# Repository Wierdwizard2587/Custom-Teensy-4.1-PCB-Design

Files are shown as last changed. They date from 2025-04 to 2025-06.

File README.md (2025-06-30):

# Custom Teensy 4.1 Microcontroller PCB

## Overview

This repository covers the design of my custom take on the Teensy 4.1 from PJRC. [Teensy 4.1 Site](https://www.pjrc.com/store/teensy41.html). I took inspiration from [jenschrs design](https://github.com/jenschr/Teensy-4.1-example) who incorporated usb-c rather than the intended USB-Micro, but lacked the SD slot, expandable RAM and flash memory, and PHY Ethernet IC and RJ45 Connection Like the original. 

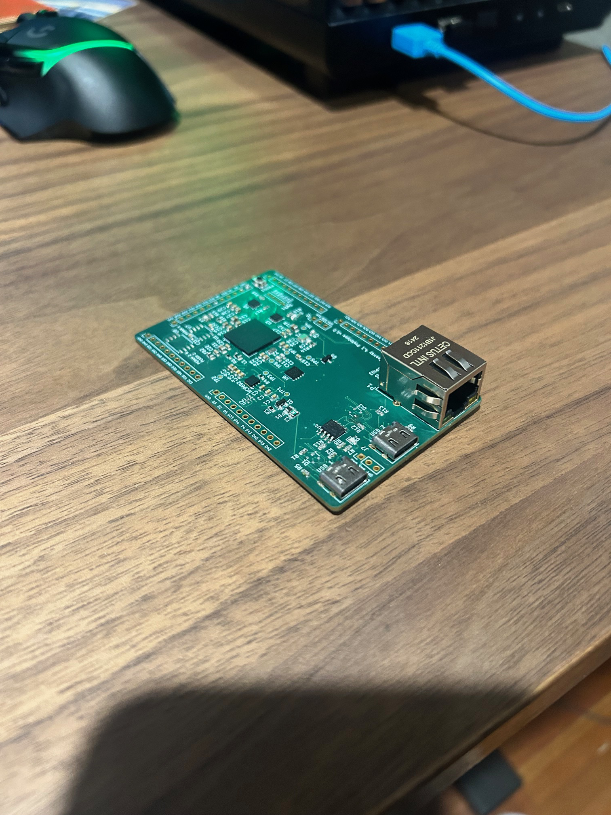
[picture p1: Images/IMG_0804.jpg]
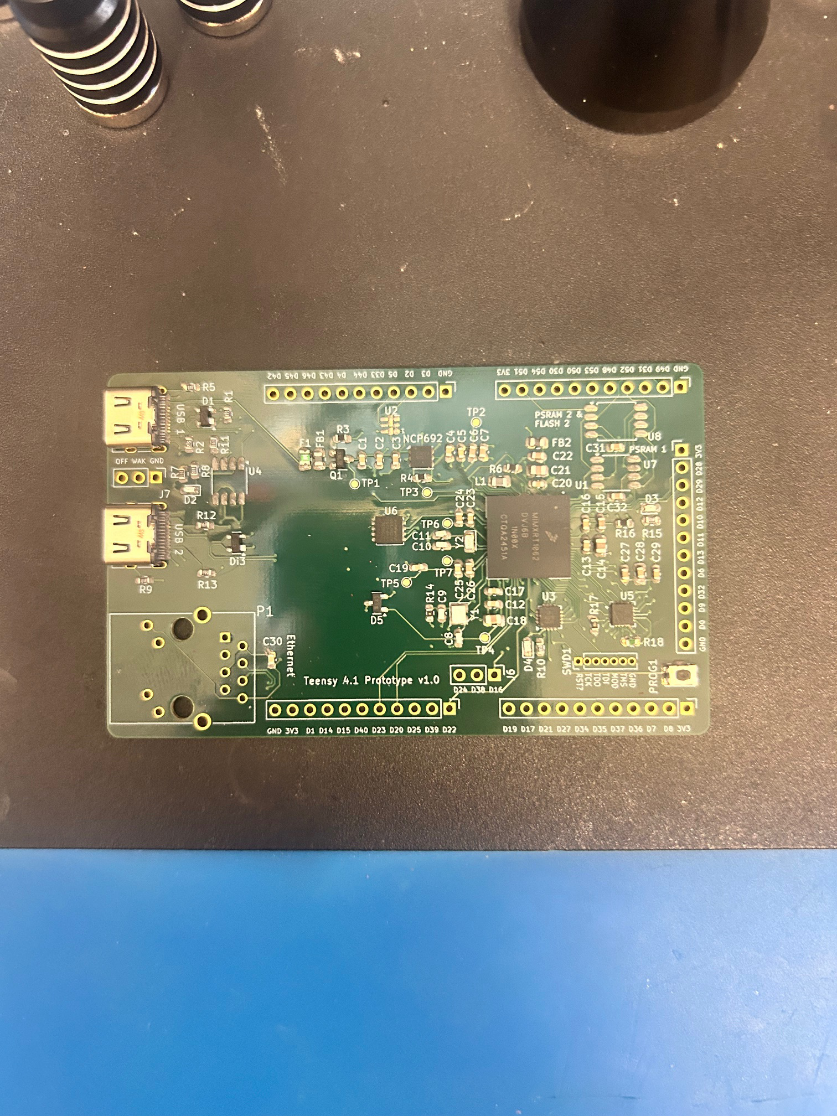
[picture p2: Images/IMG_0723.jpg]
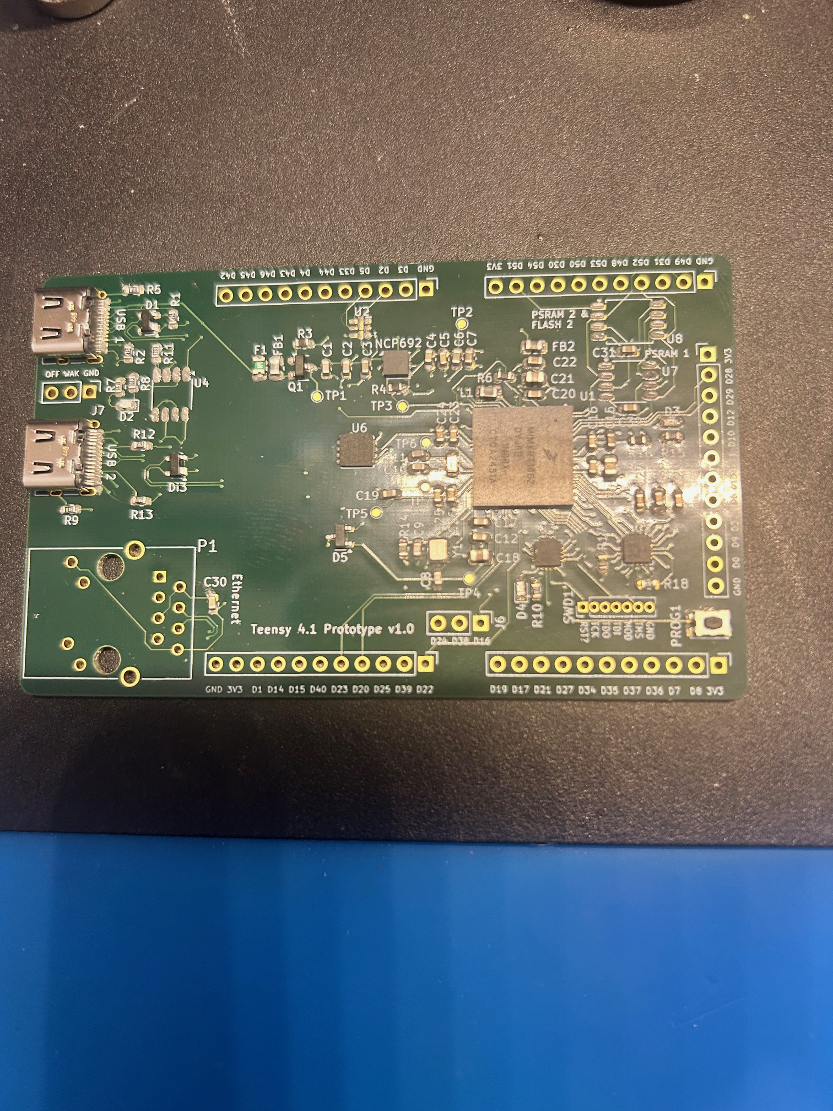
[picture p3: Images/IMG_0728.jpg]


This Design, following the Teensy 4.1 official Schematic Features a 6 layer design with dedicated GND and 3.3V plane’s, and possesses the same RAM, Flash, Boot loader and MCU components as the original Teensy 4.1, but the 3.3V regulator was swapped for a NCP692 regulator providing essentially the same specs. 

The Following are notable features in the Boards design:

- 2x USB-C connections, one for serial programming and power, and the other a host port for communication with serial to other devices
- Expandable IC footprints for a combination of either 2x additional 16mb PSRAM or 1x 16mb PSRAM and 1x 64mb FLASH
- DP83825L Ethernet PHY IC for interfacing with the MCU and the RJ45 Ethernet connector attached to the board for 10/100mbps internet
- micro SD slot

After assembling the first prototype with the supplied stencil from JLCPCB and a hot plate, and resolving a short issue from a solder bridge, The bootloader flashed the blink script to the memory and the board was able to achieve it, however serial communication wouldn’t work and windows device manager gave a error code 43. After a week of researching and forum questioning, I was able to locate the root problem to the ESD protection Diodes on the USB-C that I had used were rated for USB 2.0 and not 3.0, which was ruining the serial communication between my PC and the board. After desoldering these the board managed to show up on my PC and was finally able to communicate with it, albeit without ESD protection which can be replaced with a more suitable diode.

The Designing and assembly of this board taught me more design and assembly concepts such as:

- differential pairs and length matching design
- separation of analog and digital traces and components
- EMI ground shielding techniques
- positioning and selection of decoupling capacitors for electronic noise protection
- common via practices
- practice soldering SMD components with a hot plate and stencil effectively without overheating the temperature sensitive IC’s 
- more practical experience isolating faults in a circuit, such as isolating shorts, identifying faulty components
- examining signals with an oscilloscope to ensure Ethernet signal integrity.

all while managing to keep the design cost effective. This board is the most complex I have designed and successfully assembled to date and I am eager to take these skills learnt to the next level with the next project the future brings.

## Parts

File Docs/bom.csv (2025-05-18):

Designator | Footprint | Quantity | Value | LCSC Part #
C1, C12, C13, C17, C19, C2, C20, C23, C25, C31, C32, C4 | 0603 | 12 | 0.22uf | CC0603KRX7R6BB224
C10, C11 | 0603 | 2 | 9pF
C14, C18, C21 | 0805 | 3 | 10uf | GRM21BR71A106KA73K
C15, C22, C24, C26, C6 | 0603 | 5 | 4.7uf | CL10B475KQ8NQNC
C16, C5 | 0603 | 2 | 10nf | 0603B103K160CT
C27 | 0603 | 1 | 2.2uf | CC0603KRX7R6BB224
C28 | 0805 | 1 | 0.22uf | GRM21BR71A106KA73K
C29 | 0603 | 1 | 10nf | CL10B475KQ8NQNC
C3, C7 | 0603 | 2 | 2.2uf | CL10B225KP8NNNC
C30 | 0603 | 1 | 0.1uF | CC0603KRX7R6BB224
C8, C9 | 0603 | 2 | 10pF
D1, DI3 | SOT-143 | 2 | SP0503BAHT
D2, D3, D4 | 0603 | 3 | LED
D5 | SOT-23 | 1 | BAT54C
F1 | 0805 | 1 | Fuse | 0ZCK0050FF2E
FB1, FB2 | 0805 | 2 | Ferrite_Bead | FBMH2012HM121-T‎
J1, J2, J4, J5 | PinHeader_1x11_P2.54mm_Vertical | 4 | Conn_01x11_Male
J3 | PinHeader_1x12_P2.54mm_Vertical | 1 | Conn_01x12_Male
J6, J7 | PinHeader_1x03_P2.54mm_Vertical | 2 | Conn_01x03_Male
J8 | microSD_HC_Hirose_DM3AT-SF-PEJM5 | 1 | Micro_SD_Card
L1 | 0805 | 1 | 4.7uH | LQM21PN4R7MGRD
NCP692 | DFN-6-1EP_3x3mm_P0.95mm_EP1.7x2.6mm | 1 | OnSemi NCP692, fixed version | NCP692MN33T2G
P1 | J1B1211CCD | 1 | J1B1211CCD
PROG1 | SW_Push_1P1T-SH_NO_CK_KMR2xxG | 1 | SW_Push | KMR241GLFS
Q1 | SOT-23 | 1 | Q_PMOS_GDS_DMP3125L
R1, R2 | 0603 | 2 | 5.1k | RC0603FR-075K1L
R10, R15, R8 | 0603 | 3 | 1k
R11, R7 | 0603 | 2 | 16k
R12, R13 | 0603 | 2 | 56k | RMCF0603FT56K0
R14 | 0603 | 1 | 2.2M
R16, R3, R4, R6 | 0603 | 4 | 100k
R17 | 0603 | 1 | 150R
R18 | 0603 | 1 | 6.49K
R5, R9 | 0603 | 2 | 1M
SWD1 | PinHeader_1x07_P1.27mm_Vertical | 1 | SWD
TP1, TP2, TP3, TP4, TP5, TP6, TP7 | TestPoint_Pad_D1.0mm | 7 | TestPoint
U1 | BGA196C80P14X14_1200X1200X152N | 1 | MIMXRT1062DVJ6B
U2 | LED-APA102-2020 | 1 | opto_APA102-2020
U3 | QFN-16-1EP_3x3mm_P0.5mm_EP1.9x1.9mm | 1 | MKL02Z32VFG4
U4 | SO-8_3.9x4.9mm_P1.27mm | 1 | MAX1562
U5 | XCVR_DP83825IRMQR | 1 | DP83825IRMQR
U6 | XSON8_4x4mm | 1 | W25Q64JVXGIM
U7 | SOP-8_3.9x4.9mm_P1.27mm | 1 | PSRAM APS640L 3SQR (1)
U8 | SOIC-8_5.3x5.3mm_P1.27mm | 1 | 2nd PSRAM/Flash APS640L 3SQR / 25q128JVSQ (2)
USB_DFP1, USB_UFP1 | USB_C_Receptacle_HRO_TYPE-C-31-M-12 | 2 | USB_C_Receptacle_USB2.0
Y1 | Crystal_SMD_2520-4Pin_2.5x2.0mm | 1 | 24MHz
Y2 | Crystal_SMD_TXC_9HT11-2Pin_2.0x1.2mm_HandSoldering | 1 | 32.768kHz

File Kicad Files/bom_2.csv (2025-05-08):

Reference | Value | Footprint
C1 | 0.22uf | Capacitor_SMD:C_0603_1608Metric
C2 | 0.22uf | Capacitor_SMD:C_0603_1608Metric
C3 | 2.2uf | Capacitor_SMD:C_0603_1608Metric
C4 | 0.22uf | Capacitor_SMD:C_0603_1608Metric
C5 | 10nf | Capacitor_SMD:C_0603_1608Metric
C6 | 4.7uf | Capacitor_SMD:C_0603_1608Metric
C7 | 2.2uf | Capacitor_SMD:C_0603_1608Metric
C8 | 10pF | Capacitor_SMD:C_0603_1608Metric
C9 | 10pF | Capacitor_SMD:C_0603_1608Metric
C10 | 9pF | Capacitor_SMD:C_0603_1608Metric
C11 | 9pF | Capacitor_SMD:C_0603_1608Metric
C12 | 0.22uf | Capacitor_SMD:C_0603_1608Metric
C13 | 0.22uf | Capacitor_SMD:C_0603_1608Metric
C14 | 10uf | Capacitor_SMD:C_0805_2012Metric
C15 | 4.7uf | Capacitor_SMD:C_0603_1608Metric
C16 | 10nf | Capacitor_SMD:C_0603_1608Metric
C17 | 0.22uf | Capacitor_SMD:C_0603_1608Metric
C18 | 10uf | Capacitor_SMD:C_0805_2012Metric
C19 | 0.22uf | Capacitor_SMD:C_0603_1608Metric
C20 | 0.22uf | Capacitor_SMD:C_0603_1608Metric
C21 | 10uf | Capacitor_SMD:C_0805_2012Metric
C22 | 4.7uf | Capacitor_SMD:C_0603_1608Metric
C23 | 0.22uf | Capacitor_SMD:C_0603_1608Metric
C24 | 4.7uf | Capacitor_SMD:C_0603_1608Metric
C25 | 0.22uf | Capacitor_SMD:C_0603_1608Metric
C26 | 4.7uf | Capacitor_SMD:C_0603_1608Metric
C27 | 2.2uf | Capacitor_SMD:C_0603_1608Metric
C28 | 0.22uf | Capacitor_SMD:C_0805_2012Metric
C29 | 10nf | Capacitor_SMD:C_0603_1608Metric
C30 | 0.1uF | Capacitor_SMD:C_0603_1608Metric
C31 | 0.22uf | Capacitor_SMD:C_0603_1608Metric
C32 | 0.22uf | Capacitor_SMD:C_0603_1608Metric
D1 | SP0503BAHT | Package_TO_SOT_SMD:SOT-143
D2 | LED | LED_SMD:LED_0603_1608Metric
D3 | LED | LED_SMD:LED_0603_1608Metric
D4 | LED | LED_SMD:LED_0603_1608Metric
D5 | BAT54C | Package_TO_SOT_SMD:SOT-23
Di3 | SP0503BAHT | Package_TO_SOT_SMD:SOT-143
F1 | Fuse | Resistor_SMD:R_0805_2012Metric
FB1 | Ferrite_Bead | Resistor_SMD:R_0805_2012Metric
FB2 | Ferrite_Bead | Resistor_SMD:R_0805_2012Metric
J1 | Conn_01x11_Male | Connector_PinHeader_2.54mm:PinHeader_1x11_P2.54mm_Vertical
J2 | Conn_01x11_Male | Connector_PinHeader_2.54mm:PinHeader_1x11_P2.54mm_Vertical
J3 | Conn_01x12_Male | Connector_PinHeader_2.54mm:PinHeader_1x12_P2.54mm_Vertical
J4 | Conn_01x11_Male | Connector_PinHeader_2.54mm:PinHeader_1x11_P2.54mm_Vertical
J5 | Conn_01x11_Male | Connector_PinHeader_2.54mm:PinHeader_1x11_P2.54mm_Vertical
J6 | Conn_01x03_Male | Connector_PinHeader_2.54mm:PinHeader_1x03_P2.54mm_Vertical
J7 | Conn_01x03_Male | Connector_PinHeader_2.54mm:PinHeader_1x03_P2.54mm_Vertical
J8 | Micro_SD_Card | Connector_Card:microSD_HC_Hirose_DM3AT-SF-PEJM5
L1 | 4.7uH | Capacitor_SMD:C_0805_2012Metric
NCP692 | OnSemi NCP692, fixed version | Package_DFN_QFN:DFN-6-1EP_3x3mm_P0.95mm_EP1.7x2.6mm
P1 | J1B1211CCD | Teensy_Footprint_library:J1B1211CCD
PROG1 | SW_Push | Button_Switch_SMD:SW_Push_1P1T-SH_NO_CK_KMR2xxG
Q1 | Q_PMOS_GDS_DMP3125L | Package_TO_SOT_SMD:SOT-23
R1 | 5.1k | Resistor_SMD:R_0603_1608Metric
R2 | 5.1k | Resistor_SMD:R_0603_1608Metric
R3 | 100k | Resistor_SMD:R_0603_1608Metric
R4 | 100k | Resistor_SMD:R_0603_1608Metric
R5 | 1M | Resistor_SMD:R_0603_1608Metric
R6 | 100k | Resistor_SMD:R_0603_1608Metric
R7 | 16k | Resistor_SMD:R_0603_1608Metric
R8 | 1k | Resistor_SMD:R_0603_1608Metric
R9 | 1M | Resistor_SMD:R_0603_1608Metric
R10 | 1k | Resistor_SMD:R_0603_1608Metric
R11 | 16k | Resistor_SMD:R_0603_1608Metric
R12 | 56k | Resistor_SMD:R_0603_1608Metric
R13 | 56k | Resistor_SMD:R_0603_1608Metric
R14 | 2.2M | Resistor_SMD:R_0603_1608Metric
R15 | 1k | Resistor_SMD:R_0603_1608Metric
R16 | 100k | Resistor_SMD:R_0603_1608Metric
R17 | 150R | Resistor_SMD:R_0603_1608Metric
R18 | 6.49K | Resistor_SMD:R_0603_1608Metric
SWD1 | SWD | Connector_PinHeader_1.27mm:PinHeader_1x07_P1.27mm_Vertical
TP1 | TestPoint | TestPoint:TestPoint_Pad_D1.0mm
TP2 | TestPoint | TestPoint:TestPoint_Pad_D1.0mm
TP3 | TestPoint | TestPoint:TestPoint_Pad_D1.0mm
TP4 | TestPoint | TestPoint:TestPoint_Pad_D1.0mm
TP5 | TestPoint | TestPoint:TestPoint_Pad_D1.0mm
TP6 | TestPoint | TestPoint:TestPoint_Pad_D1.0mm
TP7 | TestPoint | TestPoint:TestPoint_Pad_D1.0mm
U1 | MIMXRT1062DVJ6B | Teensy_Footprint_library:BGA196C80P14X14_1200X1200X152N
U2 | opto_APA102-2020 | LED_SMD:LED-APA102-2020
U3 | MKL02Z32VFG4 | Package_DFN_QFN:QFN-16-1EP_3x3mm_P0.5mm_EP1.9x1.9mm
U4 | MAX1562 | Package_SO:SO-8_3.9x4.9mm_P1.27mm
U5 | DP83825IRMQR | Teensy_Footprint_library:XCVR_DP83825IRMQR
U6 | W25Q64JVXGIM | Teensy_Footprint_library:XSON8_4x4mm
U7 | PSRAM APS640L 3SQR (1) | Package_SO:SOP-8_3.9x4.9mm_P1.27mm
U8 | 2nd PSRAM/Flash APS640L 3SQR / 25q128JVSQ (2) | Package_SO:SOIC-8_5.3x5.3mm_P1.27mm
USB_DFP1 | USB_C_Receptacle_USB2.0 | Connector_USB:USB_C_Receptacle_HRO_TYPE-C-31-M-12
USB_UFP1 | USB_C_Receptacle_USB2.0 | Connector_USB:USB_C_Receptacle_HRO_TYPE-C-31-M-12
Y1 | 24MHz | Crystal:Crystal_SMD_2520-4Pin_2.5x2.0mm
Y2 | 32.768kHz | Crystal:Crystal_SMD_TXC_9HT11-2Pin_2.0x1.2mm_HandSoldering

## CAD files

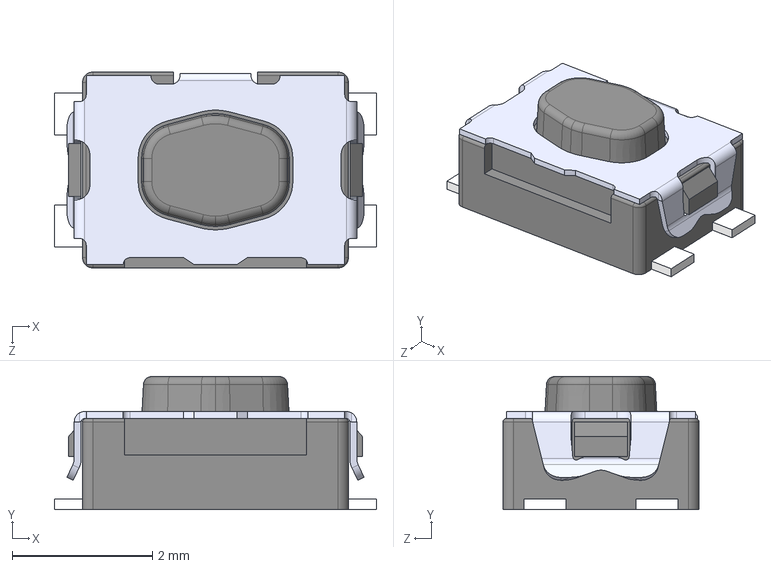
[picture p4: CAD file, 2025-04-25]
Kicad Files/Teensy_4.1_libraries/Teensy_4.1_3dModel_Library/KMR221GLFS--3DModel-STEP-56544.STEP
4.60 x 1.90 x 2.80 mm

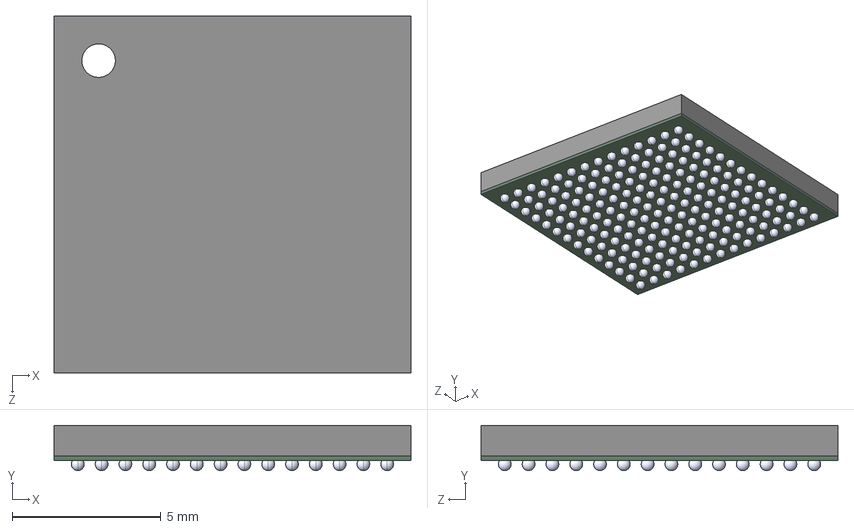
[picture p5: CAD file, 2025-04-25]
Kicad Files/Teensy_4.1_libraries/Teensy_4.1_3dModel_Library/MIMXRT1062DVJ6B.step
12.0 x 1.52 x 12.0 mm

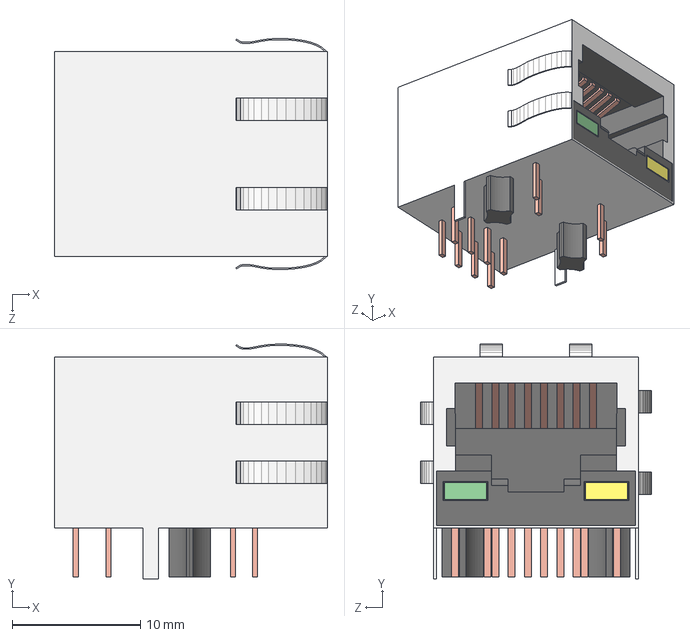
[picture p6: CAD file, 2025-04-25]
Kicad Files/Teensy_4.1_libraries/Teensy_4.1_3dModel_Library/User Library-J1B1211CCD.STEP
21.3 x 18.3 x 18.0 mm

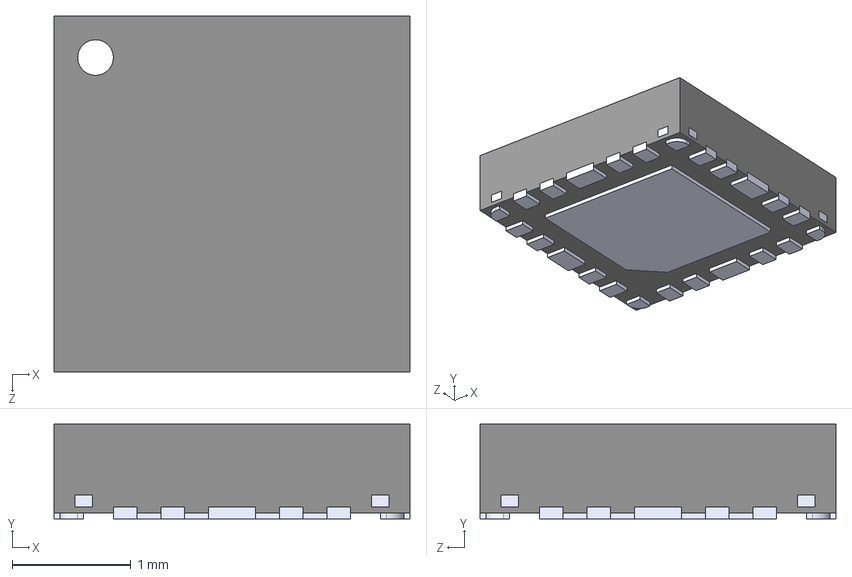
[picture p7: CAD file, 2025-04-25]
Kicad Files/Teensy_4.1_libraries/Teensy_4.1_3dModel_Library/DP83825IRMQR.step
3.00 x 0.8 x 3.00 mm

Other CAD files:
Kicad Files/Teensy_4.1_libraries/Teensy_4.1_3dModel_Library/User Library-J1B1211CCD.stl

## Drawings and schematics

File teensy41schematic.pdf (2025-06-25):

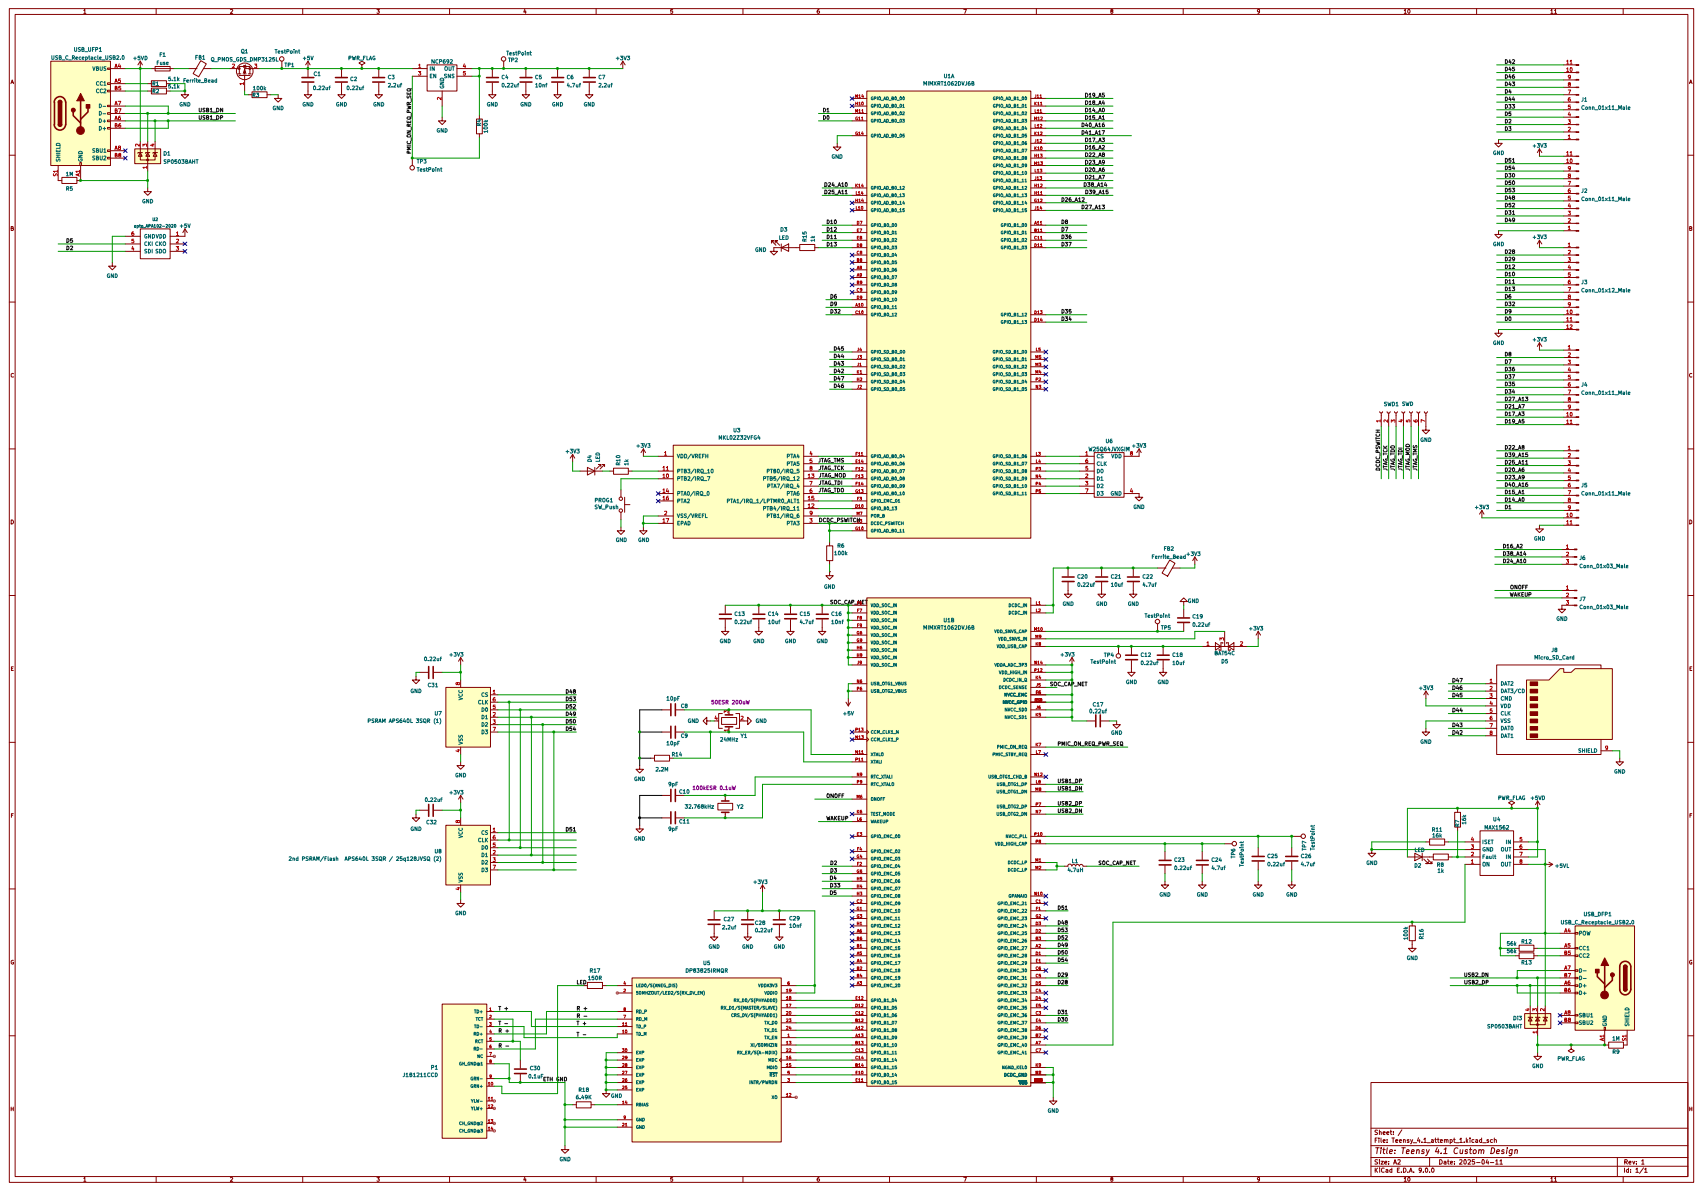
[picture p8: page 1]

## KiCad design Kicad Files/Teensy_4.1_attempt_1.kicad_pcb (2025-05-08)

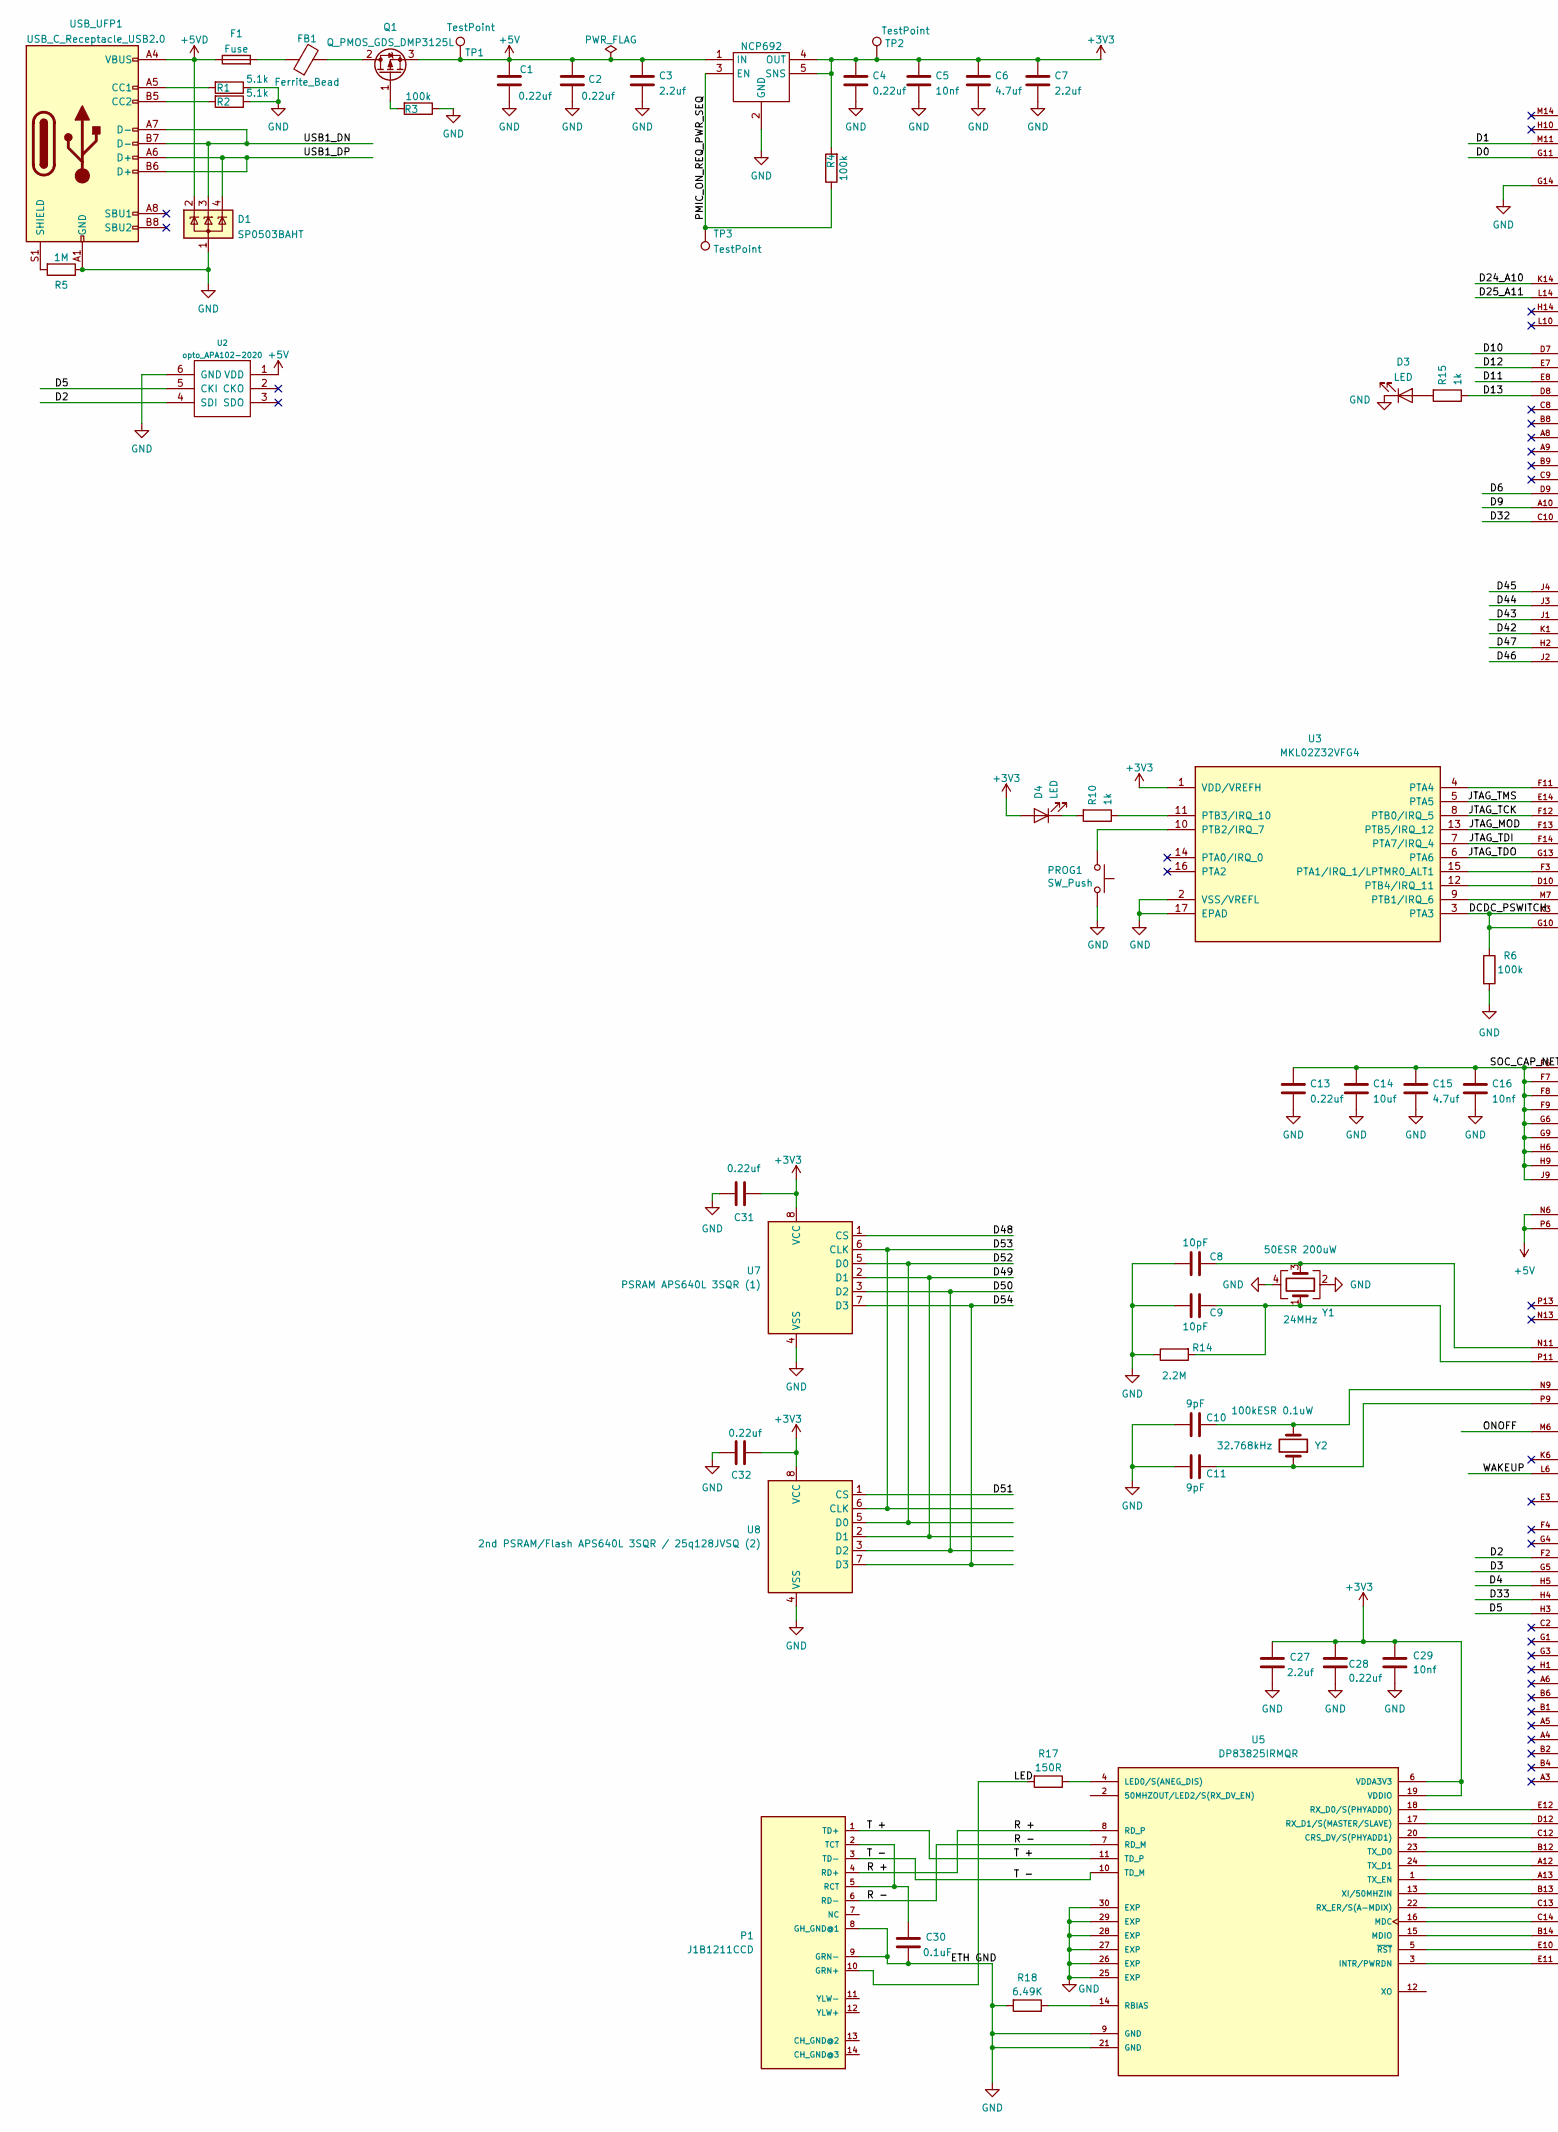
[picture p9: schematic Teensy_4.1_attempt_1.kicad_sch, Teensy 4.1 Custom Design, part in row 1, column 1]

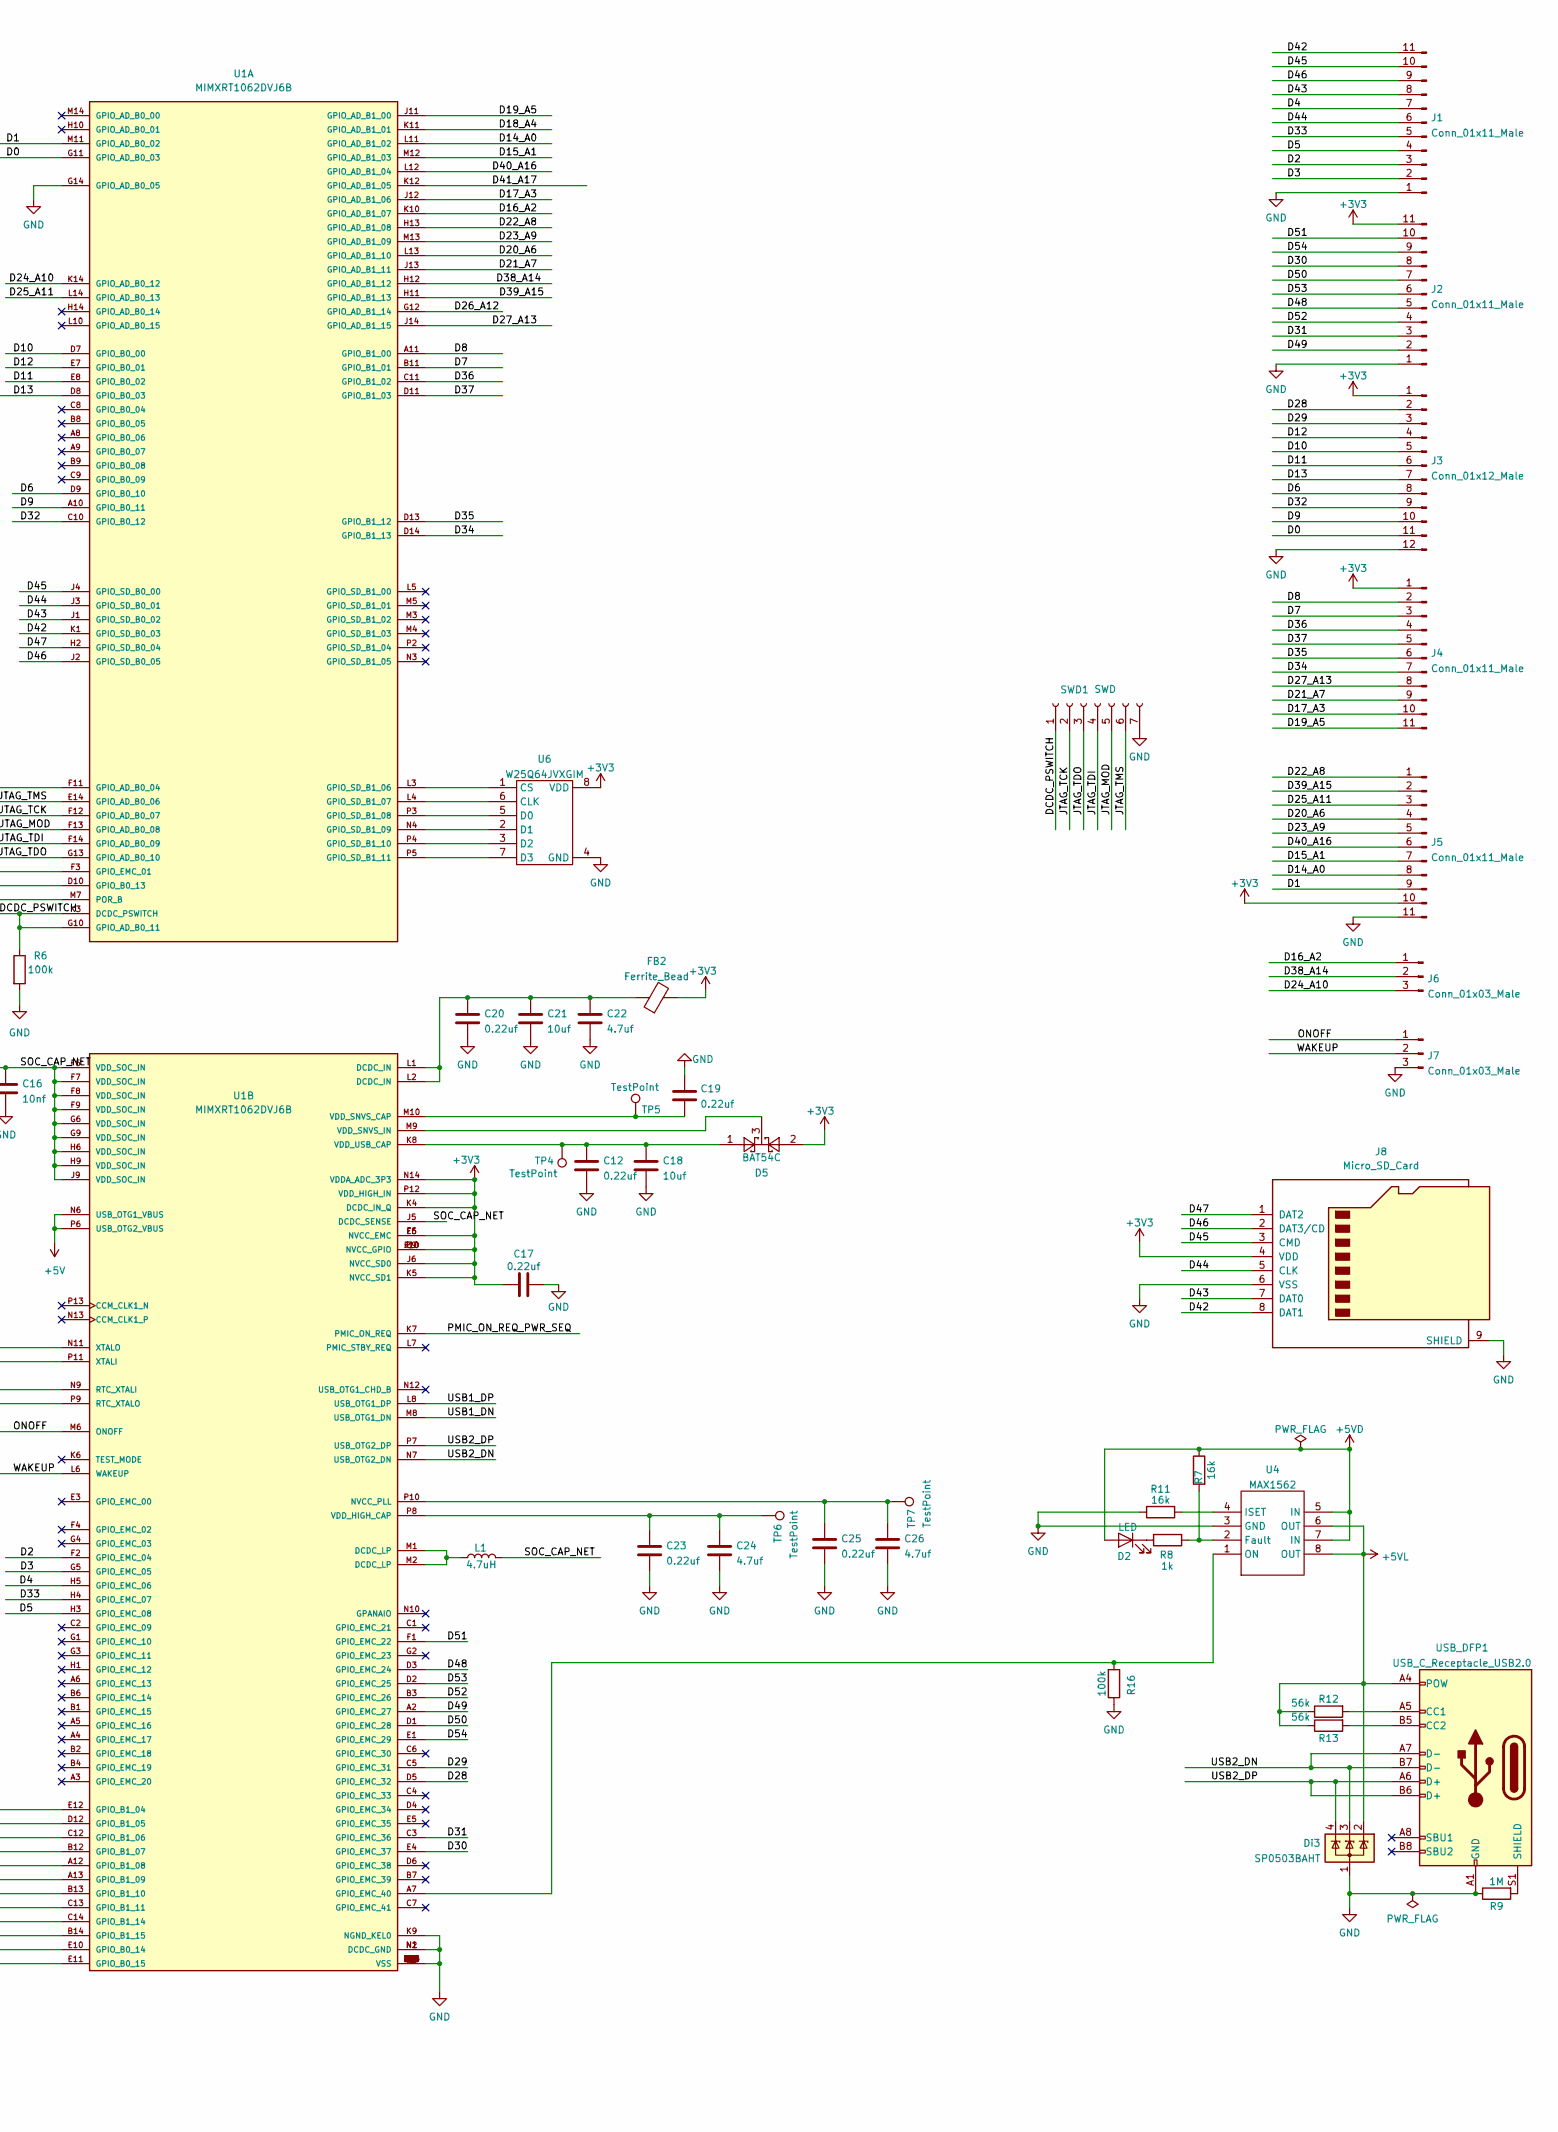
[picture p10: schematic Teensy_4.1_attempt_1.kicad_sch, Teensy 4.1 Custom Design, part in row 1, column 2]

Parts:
C1, C2, C4, C12, C13, C17, C19, C20, C23, C25, C31, C32: 0.22uf; C_0603_1608Metric; MPN CC0603KRX7R6BB224
C3, C7: 2.2uf; C_0603_1608Metric; MPN CL10B225KP8NNNC
C5, C16: 10nf; C_0603_1608Metric; MPN 0603B103K160CT
C6, C15, C22, C24, C26: 4.7uf; C_0603_1608Metric; MPN CL10B475KQ8NQNC
C8, C9: 10pF; C_0603_1608Metric
C10, C11: 9pF; C_0603_1608Metric
C14, C18, C21: 10uf; C_0805_2012Metric; MPN GRM21BR71A106KA73K
C27: 2.2uf; C_0603_1608Metric; MPN CC0603KRX7R6BB224
C28: 0.22uf; C_0805_2012Metric; MPN GRM21BR71A106KA73K
C29: 10nf; C_0603_1608Metric; MPN CL10B475KQ8NQNC
C30: 0.1uF; C_0603_1608Metric; MPN CC0603KRX7R6BB224
D1: SP0503BAHT; SOT-143
D2, D3, D4: LED; LED_0603_1608Metric
D5: BAT54C; SOT-23
Di3: SP0503BAHT; SOT-143
F1: Fuse; R_0805_2012Metric; MPN 0ZCK0050FF2E
FB1, FB2: Ferrite_Bead; R_0805_2012Metric; MPN FBMH2012HM121-T‎
J1, J2, J4, J5: Conn_01x11_Male; PinHeader_1x11_P2.54mm_Vertical
J3: Conn_01x12_Male; PinHeader_1x12_P2.54mm_Vertical
J6, J7: Conn_01x03_Male; PinHeader_1x03_P2.54mm_Vertical
J8: Micro_SD_Card; microSD_HC_Hirose_DM3AT-SF-PEJM5
L1: 4.7uH; C_0805_2012Metric; MPN LQM21PN4R7MGRD
NCP692: OnSemi NCP692, fixed version; DFN-6-1EP_3x3mm_P0.95mm_EP1.7x2.6mm; MPN NCP692MN33T2G
P1: J1B1211CCD
PROG1: SW_Push; SW_Push_1P1T-SH_NO_CK_KMR2xxG; MPN KMR241GLFS
Q1: Q_PMOS_GDS_DMP3125L; SOT-23
R1, R2: 5.1k; R_0603_1608Metric; MPN RC0603FR-075K1L
R3, R4, R6, R16: 100k; R_0603_1608Metric
R5, R9: 1M; R_0603_1608Metric
R7, R11: 16k; R_0603_1608Metric
R8, R10, R15: 1k; R_0603_1608Metric
R12, R13: 56k; R_0603_1608Metric; MPN RMCF0603FT56K0
R14: 2.2M; R_0603_1608Metric
R17: 150R; R_0603_1608Metric
R18: 6.49K; R_0603_1608Metric
SWD1: SWD; PinHeader_1x07_P1.27mm_Vertical
TP1, TP2, TP3, TP4, TP5, TP6, TP7: TestPoint; TestPoint_Pad_D1.0mm
U1: MIMXRT1062DVJ6B; BGA196C80P14X14_1200X1200X152N; PARTREV 3
U2: opto_APA102-2020; LED-APA102-2020
U3: MKL02Z32VFG4; QFN-16-1EP_3x3mm_P0.5mm_EP1.9x1.9mm
U4: MAX1562; SO-8_3.9x4.9mm_P1.27mm
U5: DP83825IRMQR; XCVR_DP83825IRMQR; PARTREV A
U6: W25Q64JVXGIM; XSON8_4x4mm
U7: PSRAM APS640L 3SQR (1); SOP-8_3.9x4.9mm_P1.27mm
U8: 2nd PSRAM/Flash APS640L 3SQR / 25q128JVSQ (2); SOIC-8_5.3x5.3mm_P1.27mm
USB_DFP1: USB_C_Receptacle_USB2.0; USB_C_Receptacle_HRO_TYPE-C-31-M-12
USB_UFP1: USB_C_Receptacle_USB2.0; USB_C_Receptacle_HRO_TYPE-C-31-M-12
Y1: 24MHz; Crystal_SMD_2520-4Pin_2.5x2.0mm
Y2: 32.768kHz; Crystal_SMD_TXC_9HT11-2Pin_2.0x1.2mm_HandSoldering

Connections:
+3V3: C4.1, C5.1, C6.1, C7.1, C17.1, C27.1, C28.1, C29.1, C31.1, C32.1, D4.2 (A), D5.2, FB2.2, J2.11, J3.1, J4.1, J5.10, J8.4 (VDD), NCP692.4 (OUT), NCP692.5 (SNS), R4.2, TP2.1, U1.E6 (NVCC_EMC), U1.E9 (NVCC_GPIO), U1.F5 (NVCC_EMC), U1.F10 (NVCC_GPIO), U1.J6 (NVCC_SD0), U1.J10 (NVCC_GPIO), U1.K4 (DCDC_IN_Q), U1.K5 (NVCC_SD1), U1.N14 (VDDA_ADC_3P3), U1.P12 (VDD_HIGH_IN), U3.1 (VDD/VREFH), U5.6 (VDDA3V3), U5.19 (VDDIO), U6.8 (VDD), U7.8 (VCC), U8.8 (VCC)
+5V: C1.1, C2.1, C3.1, NCP692.1 (IN), NCP692.6 (IN), Q1.3 (S), TP1.1, U1.N6 (USB_OTG1_VBUS), U1.P6 (USB_OTG2_VBUS), U2.1 (VDD)
+5VD: D1.2 (K), D2.2 (A), F1.1, R7.1, U4.5 (IN), U4.7 (IN), USB_UFP1.A4 (VBUS), USB_UFP1.A9 (VBUS), USB_UFP1.B4 (VBUS), USB_UFP1.B9 (VBUS)
+5VL: Di3.2 (K), R12.1, R13.1, U4.6 (OUT), U4.8 (OUT), USB_DFP1.A4 (POW), USB_DFP1.A9 (POW), USB_DFP1.B4 (POW), USB_DFP1.B9 (POW)
/D0: J3.11, U1.G11 (GPIO_AD_B0_03)
/D1: J5.9, U1.M11 (GPIO_AD_B0_02)
/D2: J1.3, U1.F2 (GPIO_EMC_04), U2.4 (SDI)
/D3: J1.2, U1.G5 (GPIO_EMC_05)
/D4: J1.7, U1.H5 (GPIO_EMC_06)
/D5: J1.4, U1.H3 (GPIO_EMC_08), U2.5 (CKI)
/D6: J3.8, U1.D9 (GPIO_B0_10)
/D7: J4.3, U1.B11 (GPIO_B1_01)
/D8: J4.2, U1.A11 (GPIO_B1_00)
/D9: J3.10, U1.A10 (GPIO_B0_11)
/D10: J3.5, U1.D7 (GPIO_B0_00)
/D11: J3.6, U1.E8 (GPIO_B0_02)
/D12: J3.4, U1.E7 (GPIO_B0_01)
/D13: J3.7, R15.1, U1.D8 (GPIO_B0_03)
/D14_A0: J5.8, U1.L11 (GPIO_AD_B1_02)
/D15_A1: J5.7, U1.M12 (GPIO_AD_B1_03)
/D16_A2: J6.1, U1.K10 (GPIO_AD_B1_07)
/D17_A3: J4.10, U1.J12 (GPIO_AD_B1_06)
/D18_A4: U1.K11 (GPIO_AD_B1_01)
/D19_A5: J4.11, U1.J11 (GPIO_AD_B1_00)
/D20_A6: J5.4, U1.L13 (GPIO_AD_B1_10)
/D21_A7: J4.9, U1.J13 (GPIO_AD_B1_11)
/D22_A8: J5.1, U1.H13 (GPIO_AD_B1_08)
/D23_A9: J5.5, U1.M13 (GPIO_AD_B1_09)
/D24_A10: J6.3, U1.K14 (GPIO_AD_B0_12)
/D25_A11: J5.3, U1.L14 (GPIO_AD_B0_13)
/D26_A12: U1.G12 (GPIO_AD_B1_14)
/D27_A13: J4.8, U1.J14 (GPIO_AD_B1_15)
/D28: J3.2, U1.D5 (GPIO_EMC_32)
/D29: J3.3, U1.C5 (GPIO_EMC_31)
/D30: J2.8, U1.E4 (GPIO_EMC_37)
/D31: J2.3, U1.C3 (GPIO_EMC_36)
/D32: J3.9, U1.C10 (GPIO_B0_12)
/D33: J1.5, U1.H4 (GPIO_EMC_07)
/D34: J4.7, U1.D14 (GPIO_B1_13)
/D35: J4.6, U1.D13 (GPIO_B1_12)
/D36: J4.4, U1.C11 (GPIO_B1_02)
/D37: J4.5, U1.D11 (GPIO_B1_03)
/D38_A14: J6.2, U1.H12 (GPIO_AD_B1_12)
/D39_A15: J5.2, U1.H11 (GPIO_AD_B1_13)
/D40_A16: J5.6, U1.L12 (GPIO_AD_B1_04)
/D41_A17: U1.K12 (GPIO_AD_B1_05)
/D42: J1.11, J8.8 (DAT1), U1.K1 (GPIO_SD_B0_03)
/D43: J1.8, J8.7 (DAT0), U1.J1 (GPIO_SD_B0_02)
/D44: J1.6, J8.5 (CLK), U1.J3 (GPIO_SD_B0_01)
/D45: J1.10, J8.3 (CMD), U1.J4 (GPIO_SD_B0_00)
/D46: J1.9, J8.2 (DAT3/CD), U1.J2 (GPIO_SD_B0_05)
/D47: J8.1 (DAT2), U1.H2 (GPIO_SD_B0_04)
/D48: J2.5, U1.D3 (GPIO_EMC_24), U7.1 (CS)
/D49: J2.2, U1.A2 (GPIO_EMC_27), U7.2 (D1), U8.2 (D1)
/D50: J2.7, U1.D1 (GPIO_EMC_28), U7.3 (D2), U8.3 (D2)
/D51: J2.10, U1.F1 (GPIO_EMC_22), U8.1 (CS)
/D52: J2.4, U1.B3 (GPIO_EMC_26), U7.5 (D0), U8.5 (D0)
/D53: J2.6, U1.D2 (GPIO_EMC_25), U7.6 (CLK), U8.6 (CLK)
/D54: J2.9, U1.E1 (GPIO_EMC_29), U7.7 (D3), U8.7 (D3)
/DCDC_PSWITCH: R6.1, SWD1.1, U1.G10 (GPIO_AD_B0_11), U1.K3 (DCDC_PSWITCH), U3.3 (PTA3)
/JTAG_MOD: SWD1.5, U1.F13 (GPIO_AD_B0_08), U3.13 (PTB5/IRQ_12)
/JTAG_TCK: SWD1.2, U1.F12 (GPIO_AD_B0_07), U3.8 (PTB0/IRQ_5)
/JTAG_TDI: SWD1.4, U1.F14 (GPIO_AD_B0_09), U3.7 (PTA7/IRQ_4)
/JTAG_TDO: SWD1.3, U1.G13 (GPIO_AD_B0_10), U3.6 (PTA6)
/JTAG_TMS: SWD1.6, U1.E14 (GPIO_AD_B0_06), U3.5 (PTA5)
/LED: P1.10 (GRN+), R17.2
/ONOFF: J7.1, U1.M6 (ONOFF)
/PMIC_ON_REQ_PWR_SEQ: NCP692.3 (EN), R4.1, TP3.1, U1.K7 (PMIC_ON_REQ)
/R +: P1.4 (RD+), U5.8 (RD_P)
/R -: P1.6 (RD-), U5.7 (RD_M)
/SOC_CAP_NET: C13.1, C14.1, C15.1, C16.1, L1.2, U1.F6 (VDD_SOC_IN), U1.F7 (VDD_SOC_IN), U1.F8 (VDD_SOC_IN), U1.F9 (VDD_SOC_IN), U1.G6 (VDD_SOC_IN), U1.G9 (VDD_SOC_IN), U1.H6 (VDD_SOC_IN), U1.H9 (VDD_SOC_IN), U1.J5 (DCDC_SENSE), U1.J9 (VDD_SOC_IN)
/T +: P1.1 (TD+), U5.11 (TD_P)
/T -: P1.3 (TD-), U5.10 (TD_M)
/USB1_DN: D1.3 (K), U1.M8 (USB_OTG1_DN), USB_UFP1.A7 (D-), USB_UFP1.B7 (D-)
/USB1_DP: D1.4 (K), U1.L8 (USB_OTG1_DP), USB_UFP1.A6 (D+), USB_UFP1.B6 (D+)
/USB2_DN: Di3.3 (K), U1.N7 (USB_OTG2_DN), USB_DFP1.A7 (D-), USB_DFP1.B7 (D-)
/USB2_DP: Di3.4 (K), U1.P7 (USB_OTG2_DP), USB_DFP1.A6 (D+), USB_DFP1.B6 (D+)
/WAKEUP: J7.2, U1.L6 (WAKEUP)
GND: C1.2, C2.2, C3.2, C4.2, C5.2, C6.2, C7.2, C8.1, C9.1, C10.1, C11.1, C12.2, C13.2, C14.2, C15.2, C16.2, C17.2, C18.2, C19.1, C20.2, C21.2, C22.2, C23.2, C24.2, C25.2, C26.2, C27.2, C28.2, C29.2, C30.2, C31.2, C32.2, D1.1 (A), D3.1 (K), Di3.1 (A), J1.1, J2.1, J3.12, J5.11, J7.3, J8.6 (VSS), J8.9 (SHIELD), NCP692.2 (GND), NCP692.7 (GND), P1.8 (GH_GND@1), P1.9 (GRN-), PROG1.2, R1.1, R2.1, R3.1, R5.1, R6.2, R9.1, R11.1, R14.1, R16.1, R18.2, SWD1.7, U1.A1 (VSS), U1.A14 (VSS), U1.B5 (VSS), U1.B10 (VSS), U1.E2 (VSS), U1.E13 (VSS), U1.G7 (VSS), U1.G8 (VSS), U1.G14 (GPIO_AD_B0_05), U1.H7 (VSS), U1.H8 (VSS), U1.J7 (VSS), U1.J8 (VSS), U1.K2 (VSS), U1.K9 (NGND_KEL0), U1.K13 (VSS), U1.L9 (VSS), U1.N1 (DCDC_GND), U1.N2 (DCDC_GND), U1.N5 (VSS), U1.N8 (VSS), U1.P1 (VSS), U1.P14 (VSS), U2.6 (GND), U3.2 (VSS/VREFL), U3.17 (EPAD), U4.3 (GND), U5.9 (GND), U5.21 (GND), U5.25 (EXP), U5.26 (EXP), U5.27 (EXP), U5.28 (EXP), U5.29 (EXP), U5.30 (EXP), U6.4 (GND), U7.4 (VSS), U8.4 (VSS), USB_DFP1.A1 (GND), USB_DFP1.A12 (GND), USB_DFP1.B1 (GND), USB_DFP1.B12 (GND), USB_UFP1.A1 (GND), USB_UFP1.A12 (GND), USB_UFP1.B1 (GND), USB_UFP1.B12 (GND), Y1.2, Y1.4
unnamed: C20.1, C21.1, C22.1, FB2.1, U1.L1 (DCDC_IN), U1.L2 (DCDC_IN)
unnamed: D2.1 (K), R8.1
unnamed: D3.2 (A), R15.2
unnamed: D4.1 (K), R10.2
unnamed: F1.2, FB1.1
unnamed: L1.1, U1.M1 (DCDC_LP), U1.M2 (DCDC_LP)
unnamed: C30.1, P1.2 (TCT), P1.5 (RCT)
unnamed: FB1.2, Q1.2 (D)
unnamed: Q1.1 (G), R3.2
unnamed: U1.F11 (GPIO_AD_B0_04), U3.4 (PTA4)
unnamed: U1.D10 (GPIO_B0_13), U3.12 (PTB4/IRQ_11)
unnamed: U1.F3 (GPIO_EMC_01), U3.15 (PTA1/IRQ_1/LPTMR0_ALT1)
unnamed: U1.L3 (GPIO_SD_B1_06), U6.1 (CS)
unnamed: U1.L4 (GPIO_SD_B1_07), U6.6 (CLK)
unnamed: U1.P3 (GPIO_SD_B1_08), U6.5 (D0)
unnamed: U1.N4 (GPIO_SD_B1_09), U6.2 (D1)
unnamed: U1.P4 (GPIO_SD_B1_10), U6.3 (D2)
unnamed: U1.P5 (GPIO_SD_B1_11), U6.7 (D3)
unnamed: U1.M7 (POR_B), U3.9 (PTB1/IRQ_6)
unnamed: U1.E10 (GPIO_B0_14), U5.5 (~RST)
unnamed: U1.E11 (GPIO_B0_15), U5.3 (INTR/PWRDN)
unnamed: U1.E12 (GPIO_B1_04), U5.18 (RX_D0/S(PHYADD0))
unnamed: U1.D12 (GPIO_B1_05), U5.17 (RX_D1/S(MASTER/SLAVE))
unnamed: U1.C12 (GPIO_B1_06), U5.20 (CRS_DV/S(PHYADD1))
unnamed: U1.B12 (GPIO_B1_07), U5.23 (TX_D0)
unnamed: U1.A12 (GPIO_B1_08), U5.24 (TX_D1)
unnamed: U1.A13 (GPIO_B1_09), U5.1 (TX_EN)
unnamed: U1.B13 (GPIO_B1_10), U5.13 (XI/50MHZIN)
unnamed: U1.C13 (GPIO_B1_11), U5.22 (RX_ER/S(A-MDIX))
unnamed: U1.C14 (GPIO_B1_14), U5.16 (MDC)
unnamed: U1.B14 (GPIO_B1_15), U5.15 (MDIO)
unnamed: R16.2, U1.A7 (GPIO_EMC_40), U4.1 (ON)
unnamed: C25.1, C26.1, TP7.1, U1.P10 (NVCC_PLL)
unnamed: C10.2, U1.N9 (RTC_XTALI), Y2.2
unnamed: C11.2, U1.P9 (RTC_XTALO), Y2.1
unnamed: C23.1, C24.1, TP6.1, U1.P8 (VDD_HIGH_CAP)
unnamed: C19.2, TP5.1, U1.M10 (VDD_SNVS_CAP)
unnamed: D5.3, U1.M9 (VDD_SNVS_IN)
unnamed: C12.1, C18.1, D5.1, TP4.1, U1.K8 (VDD_USB_CAP)
unnamed: C9.2, R14.2, U1.P11 (XTALI), Y1.1
unnamed: C8.2, U1.N11 (XTALO), Y1.3
unnamed: PROG1.1, U3.10 (PTB2/IRQ_7)
unnamed: R10.1, U3.11 (PTB3/IRQ_10)
unnamed: R7.2, R8.2, U4.2 (Fault)
unnamed: R11.2, U4.4 (ISET)
unnamed: R17.1, U5.4 (LED0/S(ANEG_DIS))
unnamed: R18.1, U5.14 (RBIAS)
unnamed: R12.2, USB_DFP1.A5 (CC1)
unnamed: R13.2, USB_DFP1.B5 (CC2)
unnamed: R9.2, USB_DFP1.S1 (SHIELD)
unnamed: R1.2, USB_UFP1.A5 (CC1)
unnamed: R2.2, USB_UFP1.B5 (CC2)
unnamed: R5.2, USB_UFP1.S1 (SHIELD)

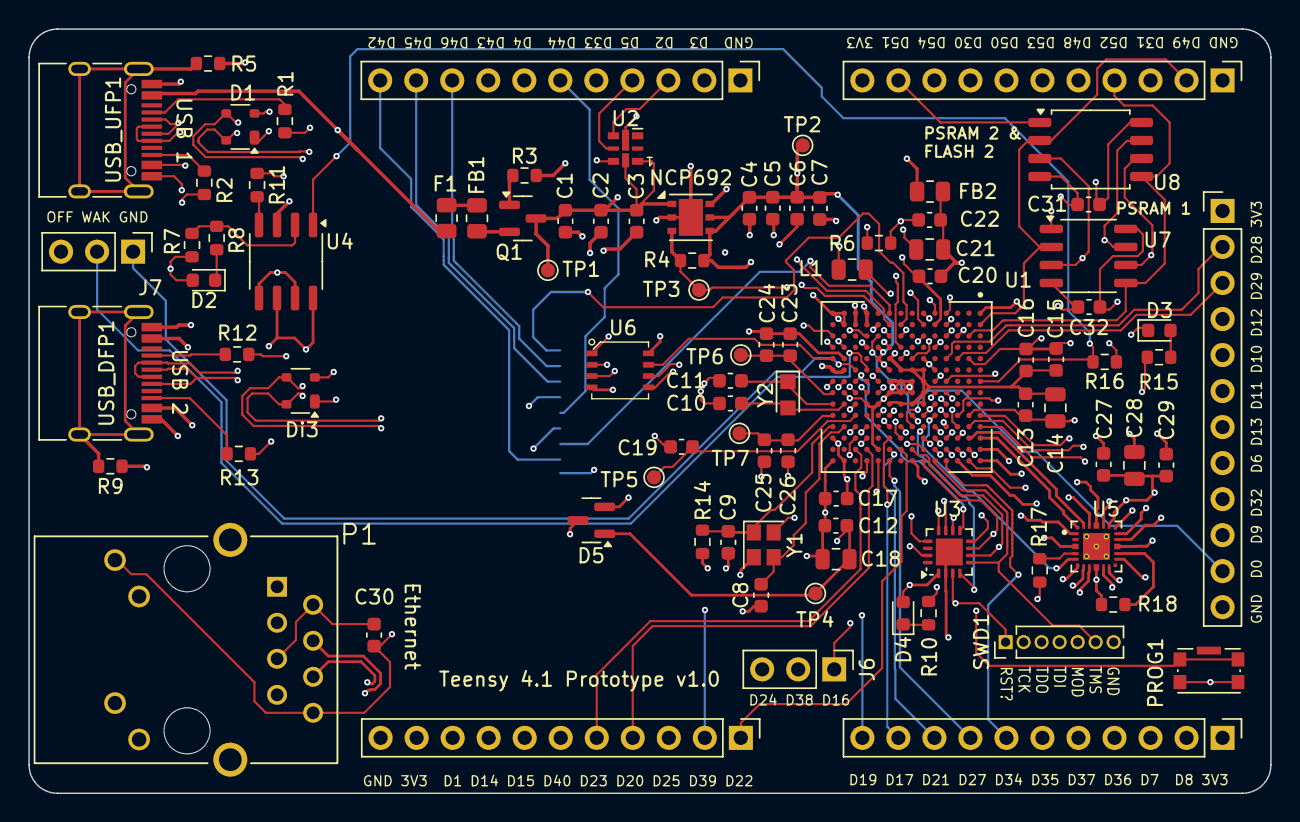
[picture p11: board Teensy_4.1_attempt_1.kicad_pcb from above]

Board: 6 copper layers, 87.6 x 53.9 mm, 92 parts (1 on the bottom side), 129 nets.

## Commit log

2025-05-08 commit BOM
    [Teensy_4.1_attempt_1.csv, Teensy_4.1_attempt_1.kicad_pcb, bom_2.csv]
2025-05-18 auto saves
    [bom.csv, designators.csv, positions.csv]
2025-06-25 Organised Repo
    [DP83825IRMQR.step, KMR221GLFS--3DModel-STEP-56544.STEP, MIMXRT1062DVJ6B.step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]
